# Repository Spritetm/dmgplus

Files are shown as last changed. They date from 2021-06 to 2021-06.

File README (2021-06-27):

GNUBOY README

  INTRO

Welcome to gnuboy, one of the few pieces of Free Software to emulate
the Game Boy handheld game console. Written in ANSI C with a few
optional assembler optimizations for particular cpus, gnuboy supports
a wide range of host systems, and has been tested successfully on:

  GNU/Linux
  FreeBSD
  OpenBSD
  BeOS
  Linux/390 (IBM S/390 Mainframe)
  SunOS/Sun Ultra60
  IRIX/SGI O2
  IRIX/SGI Indy
  AIX/Unknown
  DR-DOS
  MS-DOS
  Windows DOS box
  Windows 9x/NT/2k

Additionally, gnuboy should run on any other *nix variants that have
ANSI C compilers and that are remotely POSIX compliant. As gnuboy is
Free Software, you're welcome to fix any problems you encounter
building it for a particular system, or to port it to entirely new
systems.

  EMULATION

gnuboy emulates nearly all aspects of the (Color) Gameboy, including
all of the following and much more:

  Full GBZ80 instruction set.
  Scanline-based LCD engine.
  Ten sprites per scanline limit.
  Support for all CGB graphics extensions.
  Sprite DMA, HDMA, and GDMA.
  All four sound channels including digital samples.
  MBC1, MBC2, MBC3 (including clock), and MBC5 mappers.
  Wave pattern memory corruption when sound channel 3 is played.
  Pad, timer, divide counter, and other basic hardware registers.
  CGB double-speed CPU mode.

Aspects not emulated at this time include:

* Serial IO (link cable).
  Undocumented 'extra' ram in OAM space on Gameboy Color.
  All Super Gameboy extensions.
* GBC, HuC1, and HuC3 IR ports.
* Obscure mappers such as TAMA5.
  Sorting sprites by X coordinate in DMG mode.
  HALT instruction skipping in DMG mode.
  CPU stalls during HDMA and GDMA.

Only the two marked by * are known to affect the playability of
actual games or demos; the rest are just listed for completeness'
sake.

  FEATURES

In addition to basic emulation, gnuboy provides the following
features:

  Highly flexible keybinding and configuration subsystem.
  State saving and loading at any point.
  Very precise timing/synchronization, preserved across save/load.
  Joystick support on Linux, DOS, and all SDL-based ports.
  Fully customizable palettes for DMG games.
  Screen scaling by a factor of 2, 3, or 4 in all ports.
  Hardware-based screen scaling on platforms where it's available.
  Debug traces to stdout.
  Dynamic palette allocation when run in 256-color modes...
  OR simulated 3/3/2 bits per channel in 256-color modes.

For information on configuring and using these features, see the
additional documentation in the "docs" directory.

  COMPATIBILITY

Out of over 300 results reported by testers, all games are known to
work perfectly on gnuboy with the following exceptions:

  Fighting Phoenix (Japanese) may or may not work since it uses the
  HuC1 memory controller, which is not implemented properly. There has
  been no report either way so far.

  Pocket Bomberman (Japanese version, which uses HuC1) runs, but can
  be made to crash if the player jumps into the ceiling in the first
  level. It's not clear whether this bug is MBC-related, something
  else, or an actual bug in the original game.

  Monster Go! Go! Go! (Japanese) is unplayable. The cause of the
  problem is not fully known, but it's either a very bad dump or it's
  using some sort of specialized MBC that's not documented.

  Final Fantasy Adventure has visual problems with the fade between
  screens. Does not affect gameplay.

  Bubble Bobble 2 has some minor tile glitches right before gameplay
  actually begins. Cause unknown. Does not affect gameplay.

  Alone in the Dark is reported to have minor visual glitches. I
  haven't seen it myself so I can't judge their severity.

  Both new Zelda games are reported to have a visual glitch at the
  beginning of the game, and on certain other screens. I haven't seen
  the problem myself, but supposedly it impacts gameplay to some
  extent.

Please report any other incompatibilities discovered directly to
gnuboy@unix-fu.org, so that they can be documented and hopefully
fixed.

  FUTURE / WISHLIST

Here's a brief list of what may appear in gnuboy in the future:

  Screenshots.
  Integrated debugger.
  Super Gameboy support.
  Serial link over the internet.
  Serial link to a real Gameboy with a custom cable.
  Configurable color filters to provide more authentic LCD look.
  Custom colorization of DMG games on a per-tile basis.
  Support for more colorspaces in the hardware scaler.
  Recording audio.
  GBS player built from the same source tree.
  Full recording and playback of emulation.
  So-called "high level emulation" of certain typical dumb loops.

Features that are not likely to appear soon or at all include:

  Rumble support - this would be nice, but SDL doesn't seem to support
  force-feedback yet. We'll see about it in the long-term though.

  Eagle/2xSaI/etc. - probably not feasible since these libraries don't
  appear to be compatible with the terms of the GPL. We might work on
  our own interpolation engine eventually, but that's low priority.

  GUI/GUI-like features - such things are best handled by external
  front-ends. We might eventually add a mechanism for external
  programs to communicate with gnuboy and reconfigure it while it's
  running, however.

  Plugins - NO! The way I see it, plugins are just an attempt to work
  around the GPL. In any case, even if you are adding plugin support
  yourself, you are bound by the terms of the GPL when linking ANY
  code to gnuboy, including dynamic-linked modules. However we'd
  rather not deal with this mess to begin with.

  Compressed ROMs/Saves - this one is very iffy. On most systems, this
  is redundant; *nix users can just pipe the rom through a
  decompression program, and Windows users can just double-click or
  drag files from their favorite GUI unzipper program. Linking to zlib
  isn't really acceptable since it's massively bloated and we don't
  want to include it with gnuboy or add external dependencies. We may,
  however, write our own tiny decompressor to use at some point.

Ideas and suggestions for other features are welcome, but won't
necessarily be used. You're of course also free to add features
yourself, and if they fit well into the main tree they may eventually
get included in the official release. See the file HACKING for more
details on modifying and/or contributing.

  THANKS

Thanks goes out to everyone who's expressed interest in gnuboy by
writing -- users, porters, authors of other emulators, and so forth.
Apologies if we don't get a personal response out to everyone, but
either way, consider your feedback appreciated.

  EPILOGUE

OK, that looks like about it. More to come, stick around...

                                          -Laguna  <laguna@aerifal.cx>

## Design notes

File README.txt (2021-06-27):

These are various files for the DMGPlus project. Note that I did this over the time span
of about three years, so there's no plug-and-play recipe to build your own available;
I'd need to reverse my own work to provide that. As such, these files are only provided
as a reference, to plunder if you want to build something similar. For more information
about the DMGPlus project, refer to https://spritesmods.com/?art=dmgplus

The various subdirectories:

* kicad-pcb
This contains the PCB layout. Look at dmgplus-schematic.pdf in that directory if you only want
to look at the schematic without opening Kicad.

* fpga
This contains the Verilog sources for the Ice40 FPGA configuration. You need a proper 
Yosys/nextpnr/icestorm setup to build this.

* linux
This contains the gpio-matrix patch I had to apply to get multiple buttonpresses to work, as
well as the config I use to get the kernel startup to be fast.

* devicetree
The Linux kernel requires a custom device tree to get sound output, DPI RGB on the correct 
pins, and the mapping for the GPIO keyboard matrix; this generates that. Note that you need 
a device tree compiler (e.g. Debian package device-tree-compiler) to build this.

* spi-flash-reader
This compiles and runs under Raspbian. It allows you to read a GameBoy cartridge through the 
Ice40 FPGA via the SPI port. It also allows you to write the reproduction cartridges that are 
around, if you happen to have a similar model to mine.

This directory also contains an initial_init.sh script, which acts as a replacement init
script. It checks the cart inserted and starts up whatever's applicable.

* gnuboy
This is Gnuboy, modified to use the same SPI cart reading method to execute from the actual
cart that is inserted in the DMGPlus unit.

* conv_startupscreen
This is a tool to generate the binary ROM images that can be flashed into a cartridge to 
create a DMGPlus cart. The tool takes a png image that is used as a startup screen, a 
delay, and a game name. The FPGA will display the startup screen for the indicated delay,
the Raspberry Pi can use the game name to start up whatever is required.

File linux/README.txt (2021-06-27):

For posterity, this is:
- The config I used for the dmgplus
- The patch that adds multiple-key-press-detection to gpio-matrix-keypad

This is against the rpi-5.10.y branch of https://github.com/raspberrypi/linux. I used commit
5188f0cf6c768cc791b3283ab6a72cc02b4a2f99 as a basis.

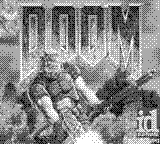
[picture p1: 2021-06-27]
conv_startupscreen/doom.png

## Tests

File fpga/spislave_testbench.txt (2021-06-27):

000
001
011
111
011
111
001
101
011
111
001
101
001
101
001
101
001
101
011
111
011
111
001
101
011
111
001
101
001
101
001
101
011
111
001
000

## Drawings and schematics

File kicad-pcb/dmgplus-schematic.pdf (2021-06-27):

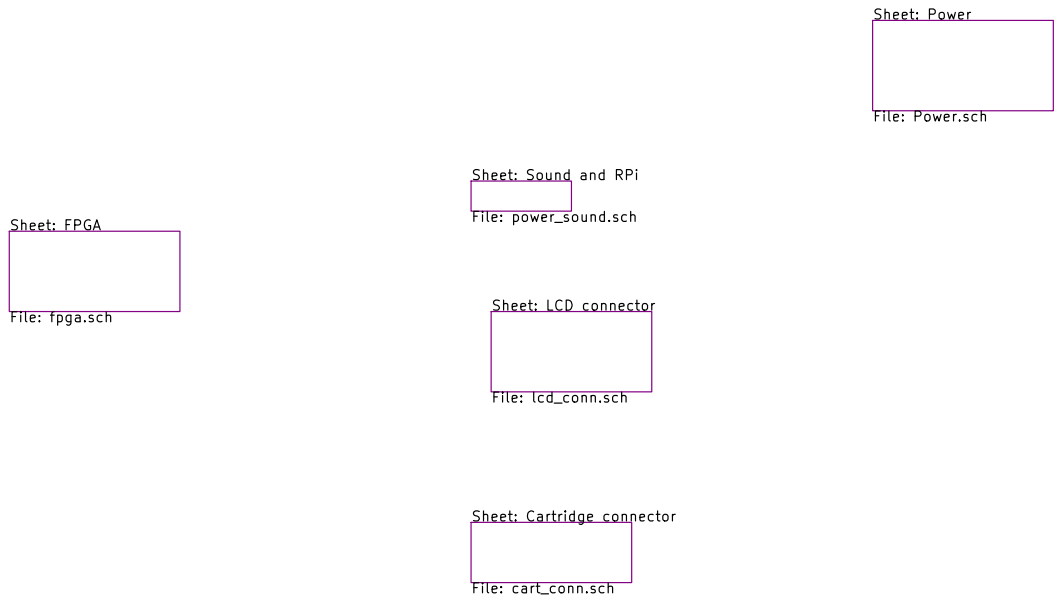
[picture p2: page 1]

Sheet: Sound and RPi File: power_sound.sch Sheet: LCD connector File: lcd_conn.sch Sheet: Cartridge connector File: cart_conn.sch Sheet: FPGA

File: dmgplus.sch Sheet: /
Id: 1/6 Title:

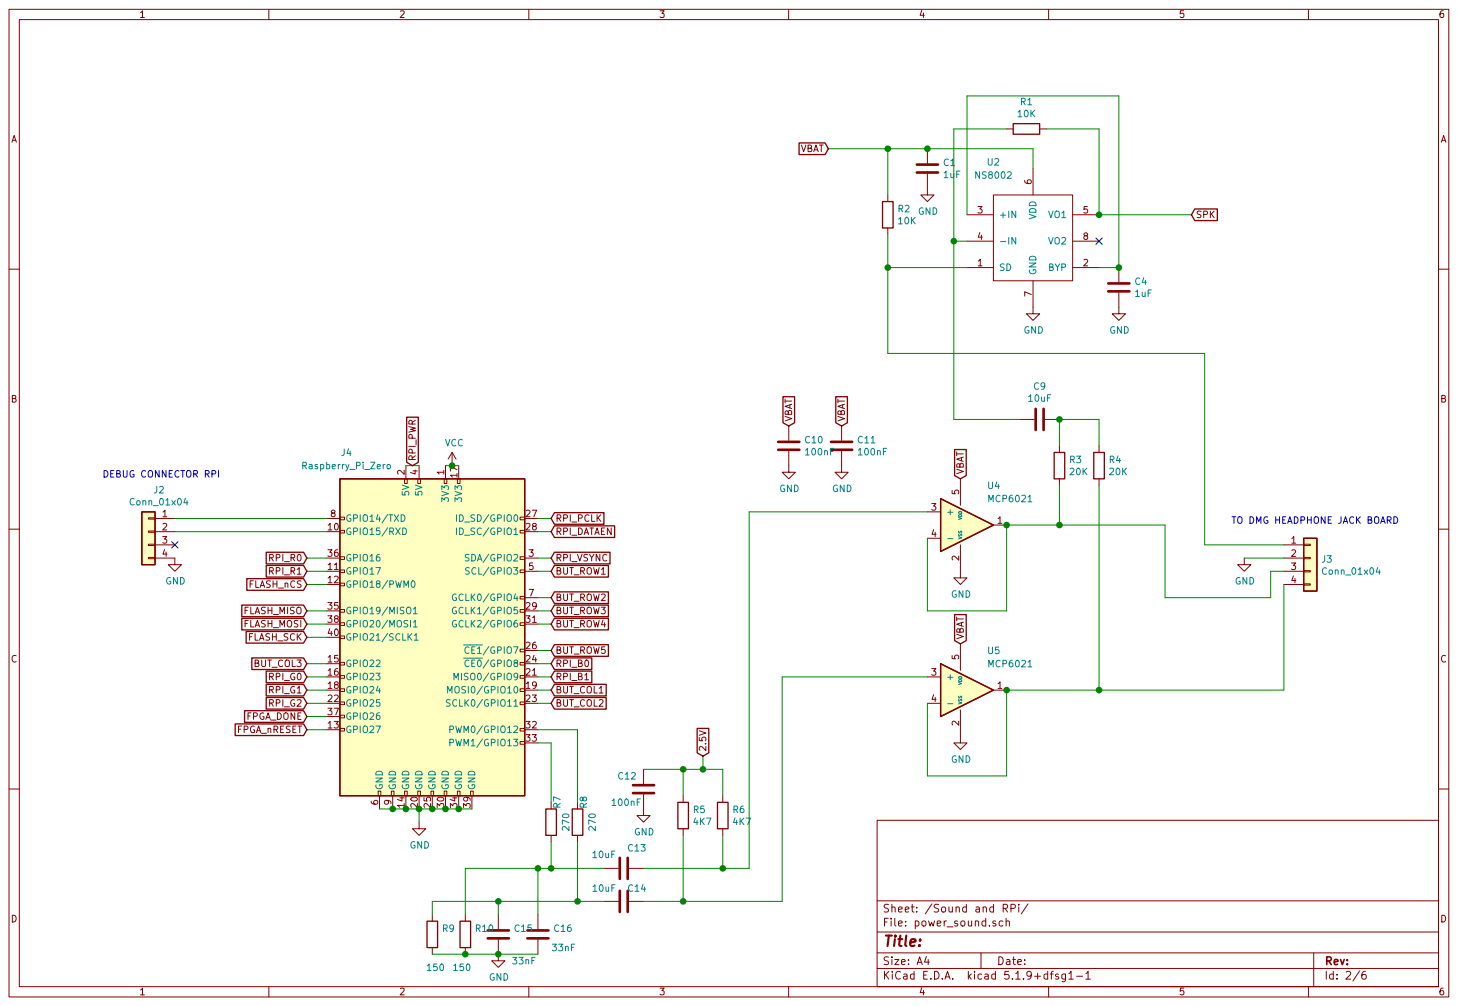
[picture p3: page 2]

File: power_sound.sch Sheet: /Sound and RPi/ C16

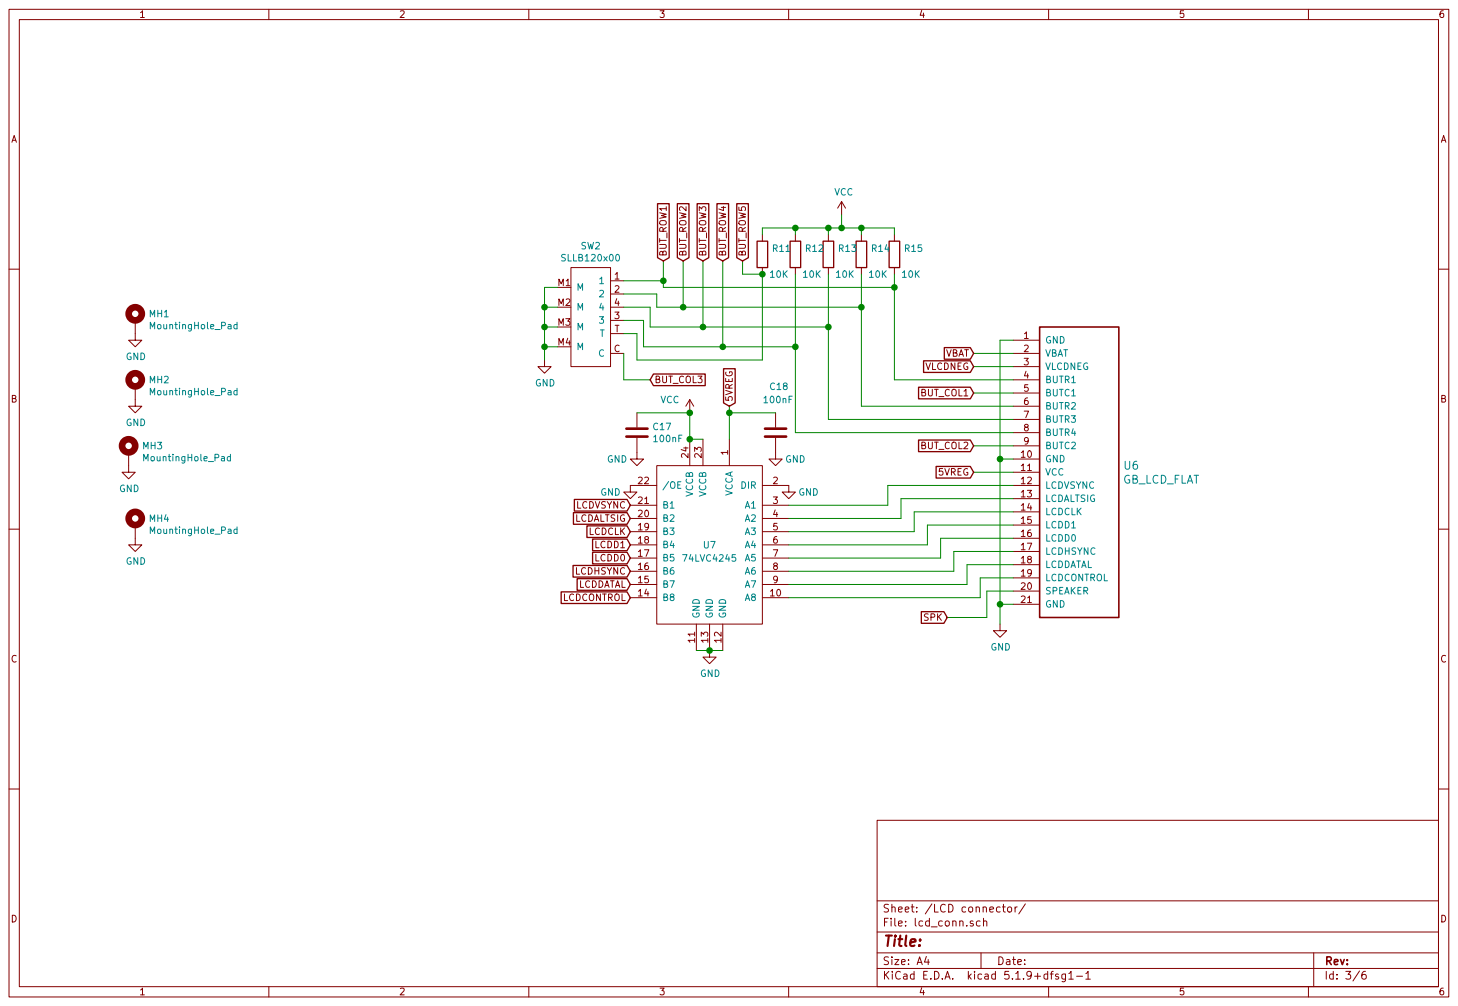
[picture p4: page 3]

1 A8 10 GND 11 GND 12 GND 13 B8 14 B7 15 B6 16 B5 17 B4 18 B3 19 DIR 2 B2 20 B1 21

LCDCLK 14
LCDD1 15
LCDD0 16
LCDHSYNC 17
LCDDATAL 18

File: lcd_conn.sch Sheet: /LCD connector/
Id: 3/6 Title:

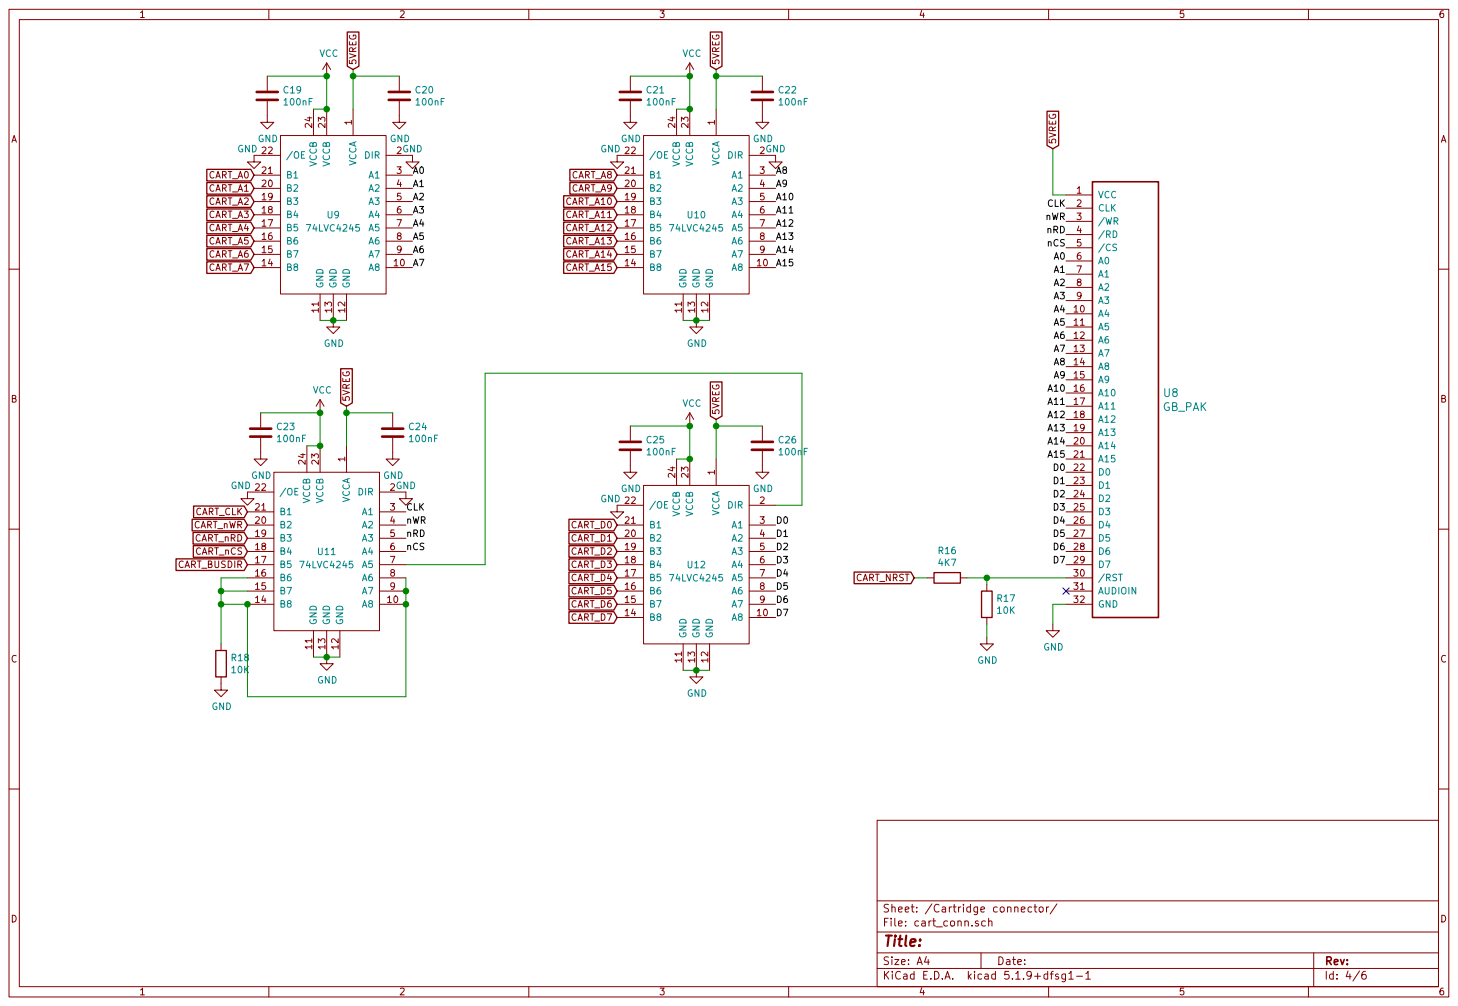
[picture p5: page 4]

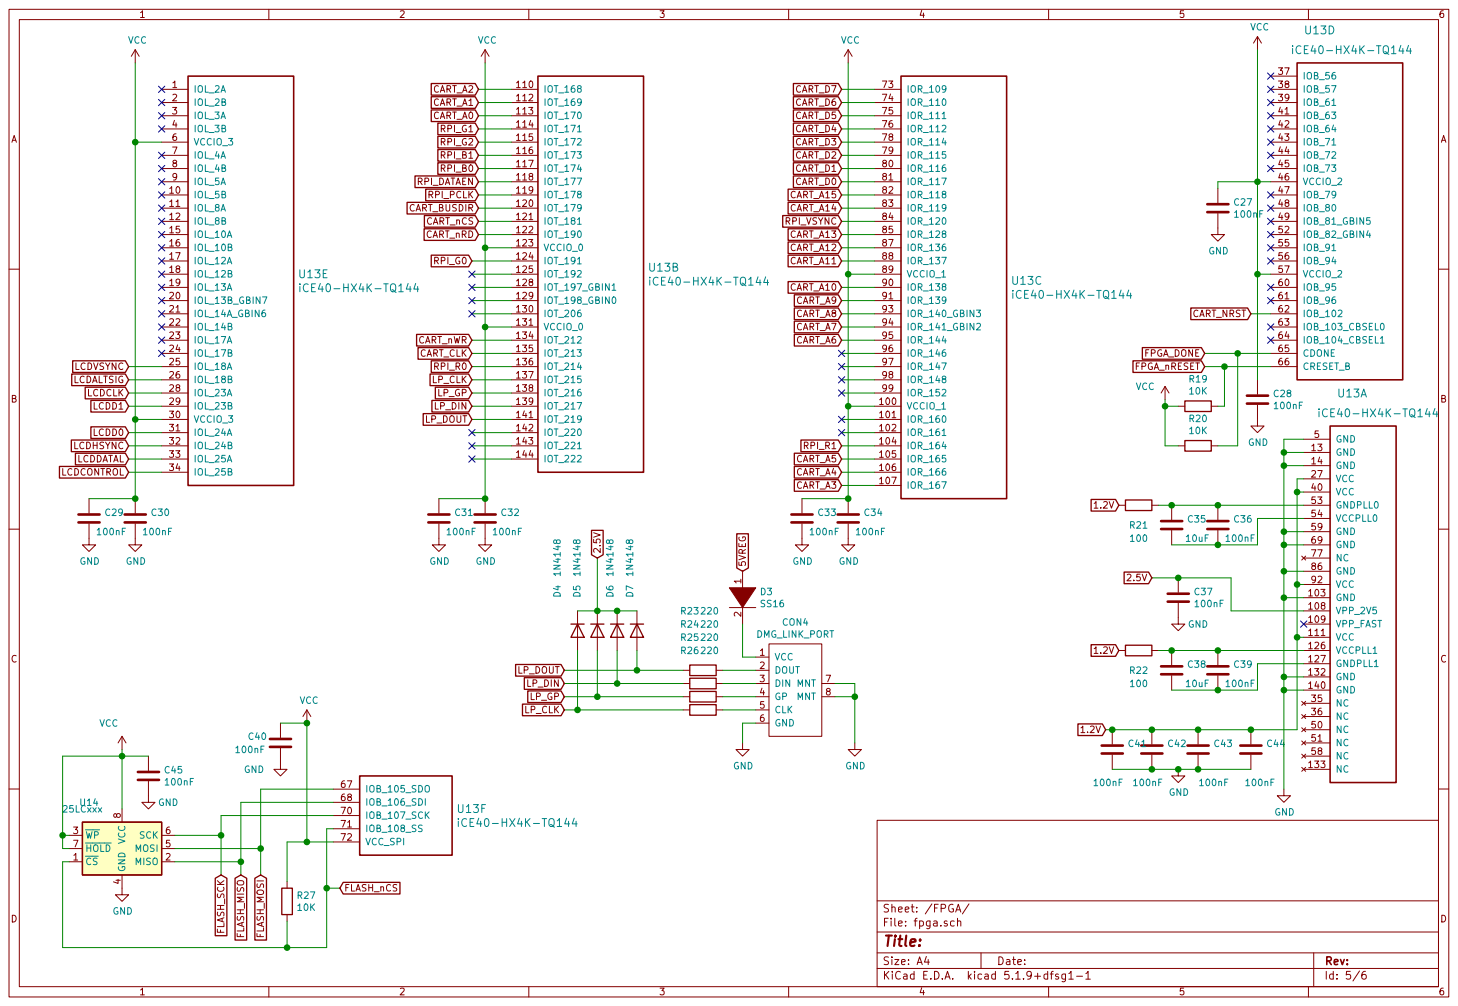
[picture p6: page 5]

File: fpga.sch Sheet: /FPGA/ C40

IOB_106_SDI 68
IOB_107_SCK 70

4 MOSI 5 SCK 6 HOLD 7 VCC

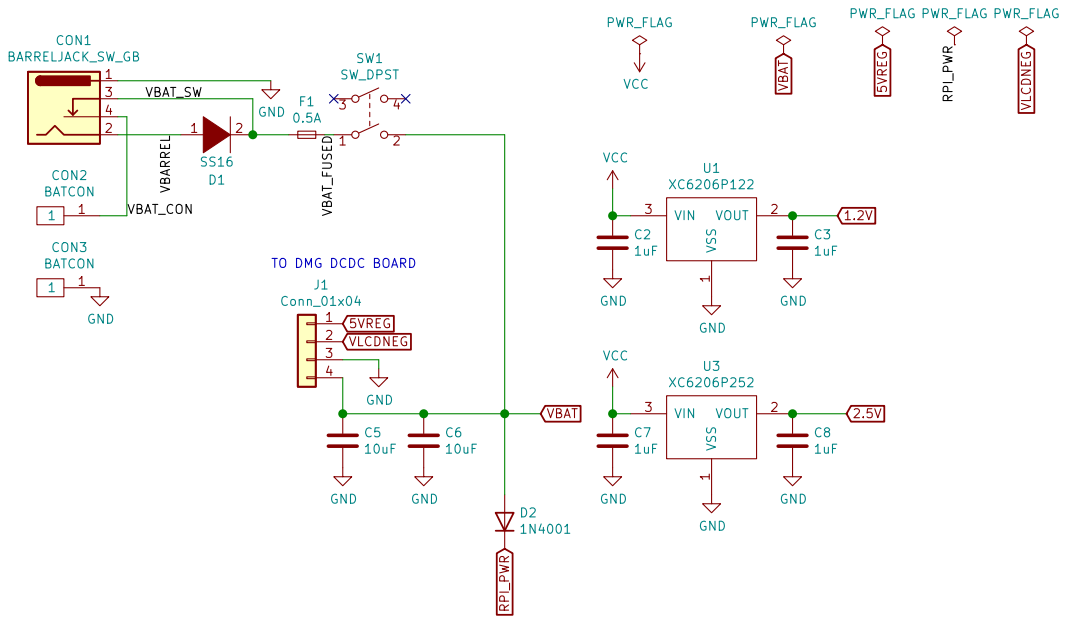
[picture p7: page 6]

Id: 6/6 Title: File: Power.sch Sheet: /Power/

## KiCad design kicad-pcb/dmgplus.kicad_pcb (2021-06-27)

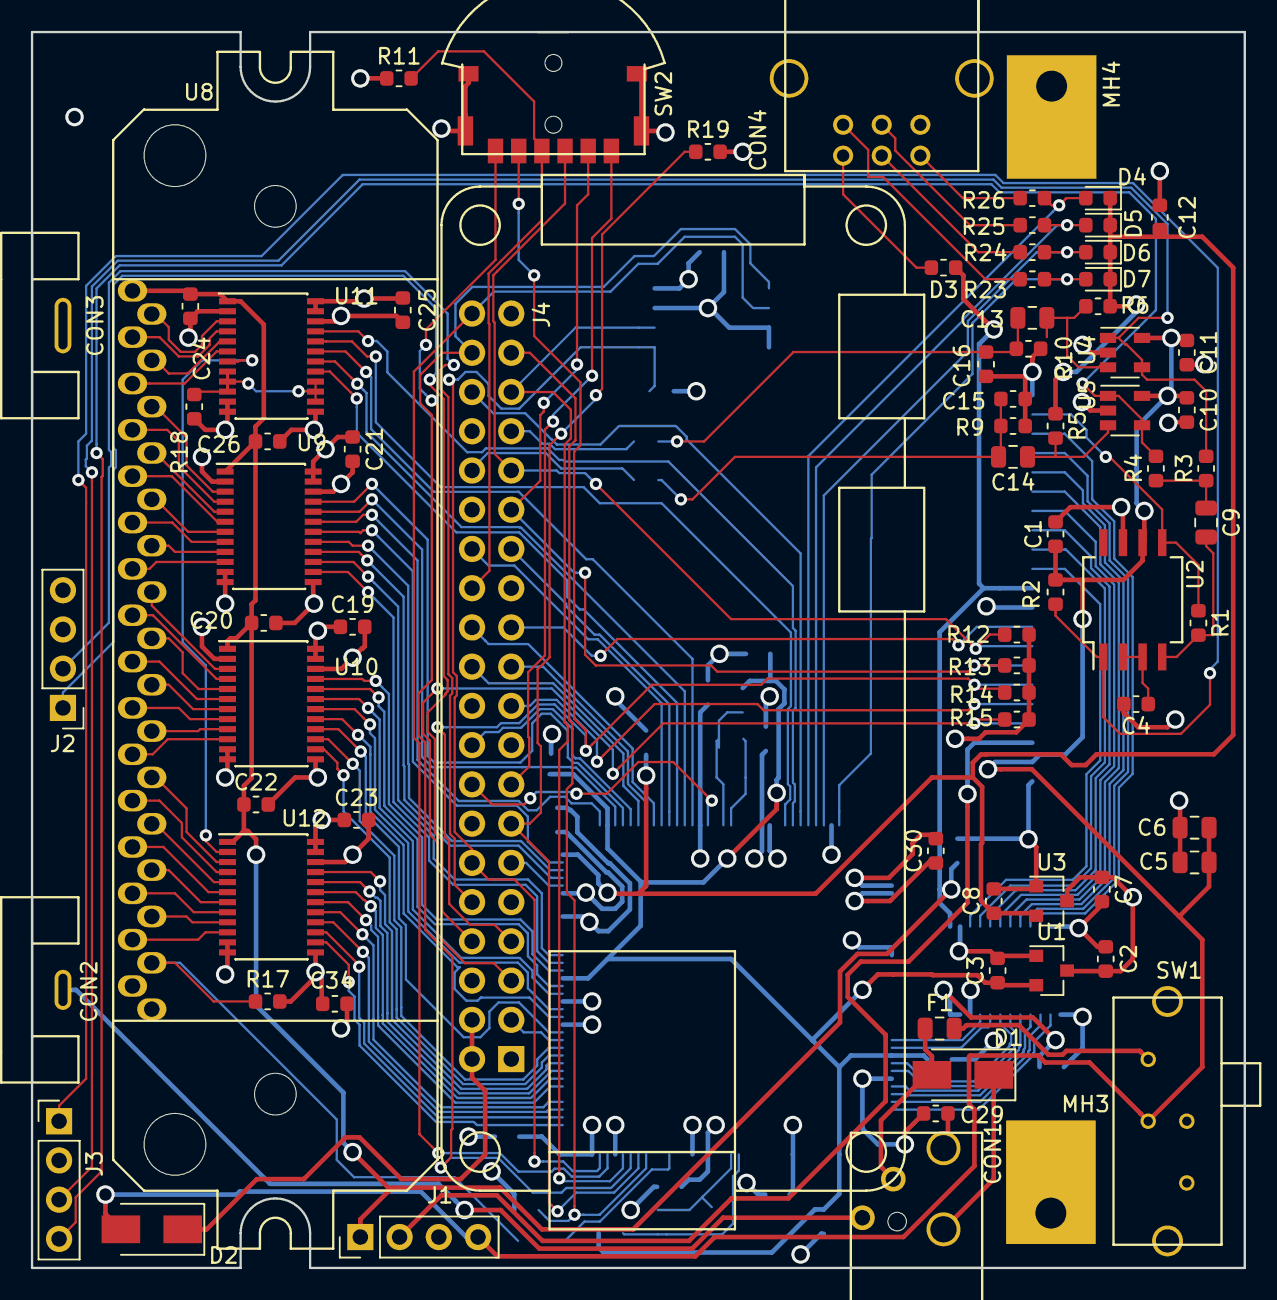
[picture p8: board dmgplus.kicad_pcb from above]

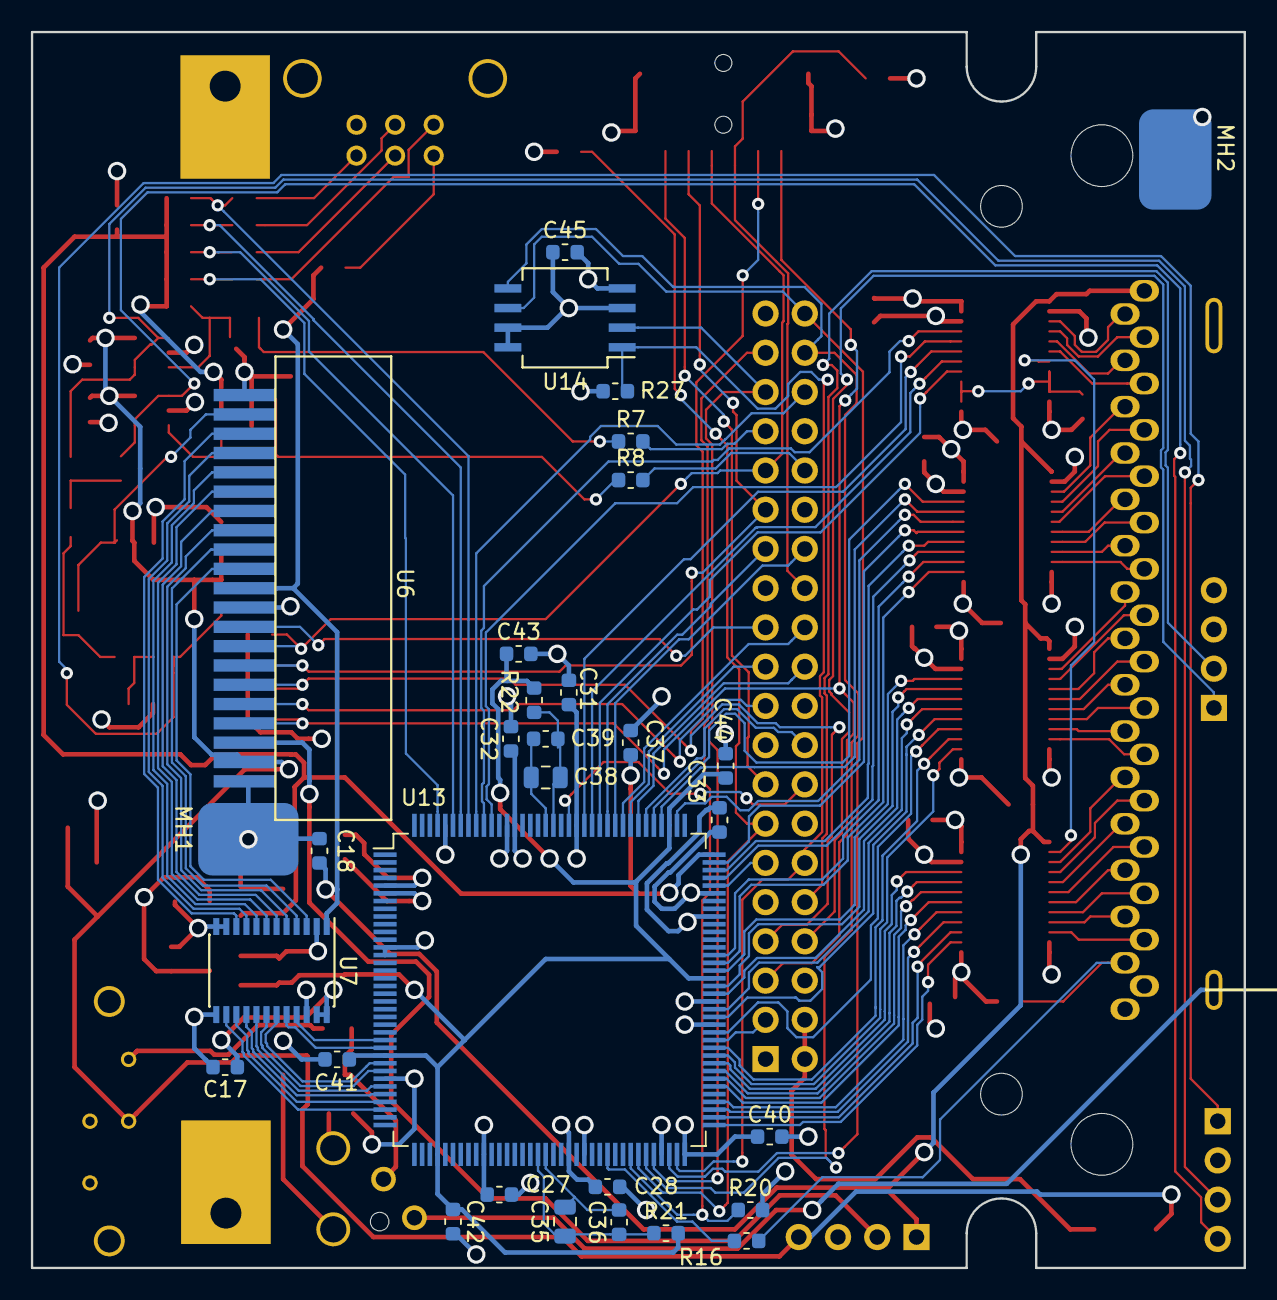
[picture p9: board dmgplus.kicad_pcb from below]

Board: 4 copper layers, 78.5 x 80.0 mm, 108 parts (31 on the bottom side), 141 nets.

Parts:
C1, C2, C3, C4, C7, C8: 1uF; C_0603_1608Metric
C5, C6, C9, C13, C14, C35, C38: 10uF; C_0805_2012Metric
C10, C11, C12, C17, C18, C19, C20, C21, C22, C23, C24, C25, C26, C27, C28, C29, C30, C31, C32, C33, C34, C36, C37, C39, C40, C41, C42, C43, C44, C45: 100nF; C_0603_1608Metric
C15, C16: 33nF; C_0603_1608Metric
CON1: BARRELJACK_SW_GB; dmg_pwrjack
CON2: BATCON; dmg_batcon_pos
CON3: BATCON; dmg_batcon_neg
CON4: DMG_LINK_PORT; dmg_linkport
D1: SS16; D_SMA
D2: 1N4001; D_SMA
D3: SS16; R_0603_1608Metric
D4, D5, D6, D7: 1N4148; D_0603_1608Metric
F1: 0.5A; Fuse_0805_2012Metric
J1, J2, J3: Conn_01x04; PinHeader_1x04_P2.54mm_Vertical
J4: Raspberry_Pi_Zero; Raspberry Pi Zero
MH1, MH2: MountingHole_Pad; dmg_grounding_square
MH3, MH4: MountingHole_Pad; dmg_groundhole_square
R1, R2, R11, R12, R13, R14, R15, R17, R18, R19, R20, R27: 10K; R_0603_1608Metric
R3, R4: 20K; R_0603_1608Metric
R5, R6, R16: 4K7; R_0603_1608Metric
R7, R8: 270; R_0603_1608Metric
R9, R10: 150; R_0603_1608Metric
R21, R22: 100; R_0603_1608Metric
R23, R24, R25, R26: 220; R_0603_1608Metric
SW1: SW_DPST; dmg_powersw
SW2: SLLB120x00; Alps_SLLB120x00
U1: XC6206P122; SOT-23
U2: NS8002; SO-8_5.3x6.2mm_P1.27mm
U3: XC6206P252; SOT-23
U4, U5: MCP6021; SOT-23-5
U6: GB_LCD_FLAT; fpc_conn_21pin
U7, U9, U10, U11, U12: 74LVC4245; TSSOP-24_4.4x7.8mm_P0.65mm
U8: GB_PAK; GB_CART_CONN
U13: iCE40-HX4K-TQ144; TQFP-144_20x20mm_P0.5mm
U14: 25LCxxx; SO-8_5.3x6.2mm_P1.27mm

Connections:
1.2V: C3.1, C41.1, C42.1, C43.1, C44.1, R21.2, R22.2, U1.2, U13.27, U13.40, U13.92, U13.111
2.5V: C8.1, C12.1, C37.1, D4.1, D5.1, D6.1, D7.1, R5.1, R6.1, U3.2, U13.108
5VREG: C18.1, C20.1, C22.1, C24.1, C26.1, D3.1, J1.1, U6.11, U7.1, U8.1, U9.1, U10.1, U11.1, U12.1
/Cartridge connector/A0: U8.6, U9.3
/Cartridge connector/A1: U8.7, U9.4
/Cartridge connector/A2: U8.8, U9.5
/Cartridge connector/A3: U8.9, U9.6
/Cartridge connector/A4: U8.10, U9.7
/Cartridge connector/A5: U8.11, U9.8
/Cartridge connector/A6: U8.12, U9.9
/Cartridge connector/A7: U8.13, U9.10
/Cartridge connector/A8: U8.14, U10.3
/Cartridge connector/A9: U8.15, U10.4
/Cartridge connector/A10: U8.16, U10.5
/Cartridge connector/A11: U8.17, U10.6
/Cartridge connector/A12: U8.18, U10.7
/Cartridge connector/A13: U8.19, U10.8
/Cartridge connector/A14: U8.20, U10.9
/Cartridge connector/A15: U8.21, U10.10
/Cartridge connector/CLK: U8.2, U11.3
/Cartridge connector/D0: U8.22, U12.3
/Cartridge connector/D1: U8.23, U12.4
/Cartridge connector/D2: U8.24, U12.5
/Cartridge connector/D3: U8.25, U12.6
/Cartridge connector/D4: U8.26, U12.7
/Cartridge connector/D5: U8.27, U12.8
/Cartridge connector/D6: U8.28, U12.9
/Cartridge connector/D7: U8.29, U12.10
/Cartridge connector/nCS: U8.5, U11.6
/Cartridge connector/nRD: U8.4, U11.5
/Cartridge connector/nWR: U8.3, U11.4
/Power/VBARREL: CON1.2, D1.1
/Power/VBAT_CON: CON1.4, CON2.1
/Power/VBAT_FUSED: F1.2, SW1.1
/Power/VBAT_SW: CON1.3, D1.2, F1.1
BUT_COL1: J4.19, U6.5
BUT_COL2: J4.23, U6.9
BUT_COL3: J4.15, SW2.C
BUT_ROW1: J4.5, R15.2, SW2.1, U6.4
BUT_ROW2: J4.7, R14.2, SW2.2, U6.6
BUT_ROW3: J4.29, R13.2, SW2.4, U6.7
BUT_ROW4: J4.31, R12.2, SW2.3, U6.8
BUT_ROW5: J4.26, R11.2, SW2.T
CART_A0: U9.21, U13.113
CART_A1: U9.20, U13.112
CART_A2: U9.19, U13.110
CART_A3: U9.18, U13.107
CART_A4: U9.17, U13.106
CART_A5: U9.16, U13.105
CART_A6: U9.15, U13.95
CART_A7: U9.14, U13.94
CART_A8: U10.21, U13.93
CART_A9: U10.20, U13.91
CART_A10: U10.19, U13.90
CART_A11: U10.18, U13.88
CART_A12: U10.17, U13.87
CART_A13: U10.16, U13.85
CART_A14: U10.15, U13.83
CART_A15: U10.14, U13.82
CART_BUSDIR: U11.17, U13.120
CART_CLK: U11.21, U13.135
CART_D0: U12.21, U13.81
CART_D1: U12.20, U13.80
CART_D2: U12.19, U13.79
CART_D3: U12.18, U13.78
CART_D4: U12.17, U13.76
CART_D5: U12.16, U13.75
CART_D6: U12.15, U13.74
CART_D7: U12.14, U13.73
CART_NRST: R16.2, U13.62
CART_nCS: U11.18, U13.121
CART_nRD: U11.19, U13.122
CART_nWR: U11.20, U13.134
FLASH_MISO: J4.35, U13.68, U14.2
FLASH_MOSI: J4.38, U13.67, U14.5
FLASH_SCK: J4.40, U13.70, U14.6
FLASH_nCS: J4.12, R27.2, U13.71, U14.1
FPGA_DONE: J4.37, R20.1, U13.65
FPGA_nRESET: J4.13, R19.1, U13.66
GND: C1.2, C2.2, C3.2, C4.2, C5.2, C6.2, C7.2, C8.2, C10.2, C11.2, C12.2, C15.2, C16.2, C17.2, C18.2, C19.2, C20.2, C21.2, C22.2, C23.2, C24.2, C25.2, C26.2, C27.2, C28.2, C29.2, C30.2, C31.2, C32.2, C33.2, C34.2, C37.2, C40.2, C41.2, C42.2, C43.2, C44.2, C45.2, CON1.1, CON3.1, CON4.6, CON4.7, CON4.8, J1.3, J2.4, J3.2, J4.6, J4.9, J4.14, J4.20, J4.25, J4.30, J4.34, J4.39, MH1.1, MH2.1, MH3.1, MH4.1, R9.2, R10.2, R17.2, R18.2, SW2.M1, SW2.M2, SW2.M3, SW2.M4, U1.1, U2.7, U3.1, U4.2, U5.2, U6.1, U6.10, U6.21, U7.2, U7.11, U7.12, U7.13, U7.22, U8.32, U9.2, U9.11, U9.12, U9.13, U9.22, U10.2, U10.11, U10.12, U10.13, U10.22, U11.2, U11.11, U11.12, U11.13, U11.22, U12.11, U12.12, U12.13, U12.22, U13.5, U13.13, U13.14, U13.59, U13.69, U13.86, U13.103, U13.132, U13.140, U14.4
LCDALTSIG: U7.20, U13.26
LCDCLK: U7.19, U13.28
LCDCONTROL: U7.14, U13.34
LCDD0: U7.17, U13.31
LCDD1: U7.18, U13.29
LCDDATAL: U7.15, U13.33
LCDHSYNC: U7.16, U13.32
LCDVSYNC: U7.21, U13.25
LP_CLK: D4.2, R26.2, U13.137
LP_DIN: D6.2, R24.2, U13.139
LP_DOUT: D7.2, R23.2, U13.141
LP_GP: D5.2, R25.2, U13.138
unnamed: C4.1, U2.2, U2.3
unnamed: C9.1, R3.1, R4.1
unnamed: C9.2, R1.2, U2.4
unnamed: C13.1, C16.1, R7.1, R10.1
unnamed: C13.2, R6.2, U4.3
unnamed: C14.1, R5.2, U5.3
unnamed: C14.2, C15.1, R8.1, R9.1
unnamed: C35.1, C36.1, R21.1, U13.53
unnamed: C35.2, C36.2, U13.54
unnamed: C38.1, C39.1, R22.1, U13.126
unnamed: C38.2, C39.2, U13.127
unnamed: CON4.1, D3.2
unnamed: CON4.2, R23.1
unnamed: CON4.3, R24.1
unnamed: CON4.4, R25.1
unnamed: CON4.5, R26.1
unnamed: J2.1, J4.8
unnamed: J2.2, J4.10
unnamed: J3.1, R2.2, U2.1
unnamed: J3.3, R3.2, U4.1, U4.4
unnamed: J3.4, R4.2, U5.1, U5.4
unnamed: J4.32, R8.2
unnamed: J4.33, R7.2
unnamed: R16.1, R17.1, U8.30
unnamed: R18.1, U11.8, U11.9, U11.10, U11.14, U11.15, U11.16
unnamed: U6.12, U7.3
unnamed: U6.13, U7.4
unnamed: U6.14, U7.5
unnamed: U6.15, U7.6
unnamed: U6.16, U7.7
unnamed: U6.17, U7.8
unnamed: U6.18, U7.9
unnamed: U6.19, U7.10
unnamed: U11.7, U12.2
RPI_B0: J4.24, U13.117
RPI_B1: J4.21, U13.116
RPI_DATAEN: J4.28, U13.118
RPI_G0: J4.16, U13.124
RPI_G1: J4.18, U13.114
RPI_G2: J4.22, U13.115
RPI_PCLK: J4.27, U13.119
RPI_PWR: D2.1, J4.2, J4.4
RPI_R0: J4.36, U13.136
RPI_R1: J4.11, U13.104
RPI_VSYNC: J4.3, U13.84
SPK: R1.1, U2.5, U6.20
VBAT: C1.1, C5.1, C6.1, C10.1, C11.1, D2.2, J1.4, R2.1, SW1.2, U2.6, U4.5, U5.5, U6.2
VCC: C2.1, C7.1, C17.1, C19.1, C21.1, C23.1, C25.1, C27.1, C28.1, C29.1, C30.1, C31.1, C32.1, C33.1, C34.1, C40.1, C45.1, J4.1, J4.17, R11.1, R12.1, R13.1, R14.1, R15.1, R19.2, R20.2, R27.1, U1.3, U3.3, U7.23, U7.24, U9.23, U9.24, U10.23, U10.24, U11.23, U11.24, U12.23, U12.24, U13.6, U13.30, U13.46, U13.57, U13.72, U13.89, U13.100, U13.123, U13.131, U14.3, U14.7, U14.8
VLCDNEG: J1.2, U6.3

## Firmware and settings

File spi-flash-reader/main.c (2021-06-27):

//Code to interface with the FPGA to read (and write, if possible) a GB cart.

/*
 * ----------------------------------------------------------------------------
 * "THE BEER-WARE LICENSE" (Revision 42):
 * Jeroen Domburg <jeroen@spritesmods.com> wrote this file. As long as you retain 
 * this notice you can do whatever you want with this stuff. If we meet some day, 
 * and you think this stuff is worth it, you can buy me a beer in return. 
 * ----------------------------------------------------------------------------
 */

#include <stdint.h>
#include <unistd.h>
#include <stdio.h>
#include <stdlib.h>
#include <unistd.h>
#include <getopt.h>
#include <fcntl.h>
#include <sys/ioctl.h>
#include <linux/types.h>
#include <linux/spi/spidev.h>
#include <string.h>
#include "hexdump.h"

#define ARRAY_SIZE(a) (sizeof(a) / sizeof((a)[0]))

static void die(const char *s) {
	perror(s);
	exit(1);
}


typedef struct __attribute__((packed)) {
	uint8_t entry_point[4];
	uint8_t logo[0x30];
	uint8_t title[15];
	uint8_t cgb_flag;
	uint16_t licensee_new;
	uint8_t sgb_flag;
	uint8_t type;
	uint8_t rom_size;
	uint8_t ram_size;
	uint8_t dest_code;
	uint8_t licensee_old;
	uint8_t maskrom_ver;
	uint8_t hdr_chsum;
	uint16_t rom_checksum;
} gb_header_t;

typedef struct {
	int no;
	const char *desc;
	int sz;
} no_desc_t;

const no_desc_t cart_type_desc[]={
	{0x00, "ROM ONLY"},
	{0x01, "MBC1"},
	{0x02, "MBC1+RAM"},
	{0x03, "MBC1+RAM+BATTERY"},
	{0x05, "MBC2"},
	{0x06, "MBC2+BATTERY"},
	{0x08, "ROM+RAM"},
	{0x09, "ROM+RAM+BATTERY"},
	{0x0B, "MMM01"},
	{0x0C, "MMM01+RAM"},
	{0x0D, "MMM01+RAM+BATTERY"},
	{0x0F, "MBC3+TIMER+BATTERY"},
	{0x10, "MBC3+TIMER+RAM+BATTERY"},
	{0x11, "MBC3"},
	{0x12, "MBC3+RAM"},
	{0x13, "MBC3+RAM+BATTERY"},
	{0x19, "MBC5"},
	{0x1A, "MBC5+RAM"},
	{0x1B, "MBC5+RAM+BATTERY"},
	{0x1C, "MBC5+RUMBLE"},
	{0x1D, "MBC5+RUMBLE+RAM"},
	{0x1E, "MBC5+RUMBLE+RAM+BATTERY"},
	{0x20, "MBC6"},
	{0x22, "MBC7+SENSOR+RUMBLE+RAM+BATTERY"},
	{0xFC, "POCKET CAMERA"},
	{0xFD, "BANDAI TAMA5"},
	{0xFE, "HuC3"},
	{0xFF, "HuC1+RAM+BATTERY"},
	{0, NULL}
};

const no_desc_t rom_size_desc[]={
	{0x00, "32KByte (2 banks, no mbc)"},
	{0x01, "64KByte (4 banks)"},
	{0x02, "128KByte (8 banks)"},
	{0x03, "256KByte (16 banks)"},
	{0x04, "512KByte (32 banks)"},
	{0x05, "1MByte (64 banks)  - only 63 banks used by MBC1"},
	{0x06, "2MByte (128 banks) - only 125 banks used by MBC1"},
	{0x07, "4MByte (256 banks)"},
	{0x08, "8MByte (512 banks)"},
	{0x52, "1.1MByte (72 banks)"},
	{0x53, "1.2MByte (80 banks)"},
	{0x54, "1.5MByte (96 banks)"},
	{0, NULL}
};

const no_desc_t ram_size_desc[]={
	{0x01, "2 KBytes"},
	{0x02, "8 Kbytes"},
	{0x03, "32 KBytes (4 banks of 8KBytes each)"},
	{0x04, "128 KBytes (16 banks of 8KBytes each)"},
	{0, NULL}
};

const no_desc_t lang_desc[]={
	{0x05, "64 KBytes (8 banks of 8KBytes each)00h - Japanese"},
	{0x01, "Non-Japanese"},
	{0, NULL}
};

const uint8_t ninty_logo[0x30]={
	0xCE, 0xED, 0x66, 0x66, 0xCC, 0x0D, 0x00, 0x0B, 0x03, 0x73, 
	0x00, 0x83, 0x00, 0x0C, 0x00, 0x0D, 0x00, 0x08, 0x11, 0x1F, 
	0x88, 0x89, 0x00, 0x0E, 0xDC, 0xCC, 0x6E, 0xE6, 0xDD, 0xDD, 
	0xD9, 0x99, 0xBB, 0xBB, 0x67, 0x63, 0x6E, 0x0E, 0xEC, 0xCC, 
	0xDD, 0xDC, 0x99, 0x9F, 0xBB, 0xB9, 0x33, 0x3E
};

int get_rom_bank_count(gb_header_t *hdr) {
	int v=hdr->rom_size;
	if (v<=8) {
		return 2*(1<<v);
	}
	if (v==0x52) return 72;
	if (v==0x53) return 80;
	if (v==0x54) return 96;
	return 2; //assume 32K rom
}

const char *select_desc(int no, const no_desc_t *desc) {
	static const char *ret="(unknown)";
	int i=0;
	while (desc[i].desc!=NULL) {
		if (desc[i].no==no) ret=desc[i].desc;
		i++;
	}
	return ret;
}

void show_gb_hdr_info(gb_header_t *hdr) {
	char title[17]={0};
	for (int i=0; i<16; i++) {
		if (hdr->title[i]==0 || hdr->title[i]>96) break;
		title[i]=hdr->title[i];
	}
	printf("Cart title: %s\n", title);
	printf("Cart type: %s\n", select_desc(hdr->type, cart_type_desc));
	printf("Cart size: %s\n", select_desc(hdr->rom_size, rom_size_desc));
	printf("Cart ram size: %s\n", select_desc(hdr->ram_size, ram_size_desc));
}


void gbcart_read(int fd, uint32_t addr, uint32_t len, uint8_t *buff) {
	uint8_t tx[3]={0};
	tx[0]=(addr>>8)&0x7f;
	tx[1]=addr&0xff;
	struct spi_ioc_transfer tr[3]={
		{
			.tx_buf = (unsigned long)tx,
			.len = 3,
			.cs_change=0
		},{
			.rx_buf=(unsigned long)buff,
			.len=len,
//			.delay_usecs=100,
			.cs_change=1
		},{
			.delay_usecs=5,
			.cs_change=1
		}
	};

	int ret = ioctl(fd, SPI_IOC_MESSAGE(3), tr);
	if (ret < 1) die("can't send spi message");
}

uint8_t gbcart_read_byte(int fd, uint32_t addr) {
	uint8_t ret;
	gbcart_read(fd, addr, 1, &ret);
	return ret;
}

void gbcart_write(int fd, uint32_t addr, uint32_t len, uint8_t *buff) {
	uint8_t tx[2]={0};
	tx[0]=(addr>>8)|0x80;
	tx[1]=addr&0xff;
	struct spi_ioc_transfer tr[3]={
		{
			.tx_buf = (unsigned long)tx,
			.len = 2,
			.cs_change=0
		},{
			.tx_buf=(unsigned long)buff,
			.len=len,
			.cs_change=1
		},{
			.delay_usecs=2,
			.cs_change=1
		}
	};

	int ret = ioctl(fd, SPI_IOC_MESSAGE(3), tr);
	if (ret < 1) die("can't send spi message");
}

void gbcart_write_byte(int fd, uint32_t addr, uint8_t byte) {
	gbcart_write(fd, addr, 1, &byte);
}

uint8_t mangle_flashchip_data(uint8_t byte) {
	uint8_t frobbyte=byte&0xFC;
	if (byte&1) frobbyte|=2;
	if (byte&2) frobbyte|=1;
	return frobbyte;
}

void poke_flashchip(int fd, int addr, int byte) {
	gbcart_write_byte(fd, addr, mangle_flashchip_data(byte));
}

int validate_cfi_data(uint8_t *buf) {
	if (buf[0x20]!='Q' || buf[0x22]!='R' || buf[0x24]!='Y') {
		printf("CFI data invalid. No flash cart?\n");
		return 0;
	}
	int n=buf[0x4E];
	printf("Found flash device: %d Kib\n", (1<<(n-10)));
}

void flash_wait_toggle(int fd, int addr) {
	uint8_t b1[2], b2[2];
	do {
		gbcart_read(fd, addr, 2, b1);
		gbcart_read(fd, addr, 1, b2);
//		printf("%02X %02X\n", b1[0], b2[0]);
	} while (b1[0]!=b2[0]);
}


int main(int argc, char *argv[]) {
	int ret = 0;

#if 0
	system("raspi-gpio set 18 op");
	system("raspi-gpio set 19 a4");
	system("raspi-gpio set 20 a4");
	system("raspi-gpio set 21 a4");
#endif
	
	char *dumpfile=NULL;
	int check=0;
	int dowrite=0;
	int doerase=0;
	int getname=0;
	for (int i=1; i<argc; i++) {
		if (strcmp(argv[i], "-check")==0) {
			check=1;
		} else if (strcmp(argv[i], "-getname")==0) {
			getname=1;
		} else if (strcmp(argv[i], "-write")==0) {
			dowrite=1;
		} else if (strcmp(argv[i], "-erase")==0) {
			doerase=1;
		} else if (dumpfile==NULL) {
			dumpfile=argv[i];
		} else {
			printf("Error: did not understand %s\n", argv[i]);
			printf("Usage: %s [-check] [-getname] [-write [-erase]] [dumpfile.bin]\n", argv[0]);
			exit(1);
		}
	}

	const char *device="/dev/spidev1.0";
	int mode=SPI_MODE_0|SPI_CS_HIGH;
	int speed=8000000;
	int delay_us=0;
	int bits=8;

	int fd = open(device, O_RDWR);
	if (fd < 0) die("can't open device");
	ret = ioctl(fd, SPI_IOC_WR_MODE, &mode);
	if (ret == -1) die("can't set spi mode");
	ret = ioctl(fd, SPI_IOC_WR_BITS_PER_WORD, &bits);
	if (ret == -1) die("can't set bits per word");
	ret = ioctl(fd, SPI_IOC_WR_MAX_SPEED_HZ, &speed);
	if (ret == -1) die("can't set max speed hz");

	gb_header_t hdr={0};
	gbcart_read(fd, 0x100, sizeof(hdr), (uint8_t*)&hdr);
	
	if (check || getname) {
		int hdr_ok=1;
		int logo_ok=1;
		int is_dmgplus=0;
		if (check) show_gb_hdr_info(&hdr);
		if (memcmp(hdr.logo, ninty_logo, 0x30)!=0) {
			hdr_ok=0;
			logo_ok=0;
			if (check) printf("Header check failed: Nintendo logo data corrupted.\n");
		}
		uint8_t chs=0;
		uint8_t *chsmem=(uint8_t*)&hdr.title;
		for (int i=0; i<0x19; i++) chs=chs-chsmem[i]-1;
		if (chs!=hdr.hdr_chsum) {
			hdr_ok=0;
			if (check) printf("Header check failed: Checksum error (calc %02X read %02X).\n", chs, hdr.hdr_chsum);
		}
		if (logo_ok) {
			if (memcmp(hdr.entry_point, "DMG+", 4)==0) {
				if (check) printf("Cart is DMGPlus dummy cart\n");
				is_dmgplus=1;
			}
		}
		if (getname) {
			if (hdr_ok) {
				printf("%s\n", hdr.title);
			} else if (is_dmgplus) {
				char buff[128];
				gbcart_read(fd, 0x0, 128, (uint8_t*)buff);
				printf("%s\n", buff);
			} else {
				printf("-\n");
			}
		}

		if (hdr_ok) return 0;
		if (is_dmgplus) return 2;
		return 1;
	}

	if (dumpfile && !dowrite) {
		show_gb_hdr_info(&hdr);
		FILE *out=fopen(dumpfile, "wb");
		if (out==NULL) die(dumpfile);
		uint8_t rdata[256];
		int bankcnt=get_rom_bank_count(&hdr);

		for (int bankno=0; bankno<bankcnt; bankno++) {
			int addr;
			if (bankno==0) {
				addr=0;
			} else {
				addr=0x4000;
				uint8_t w[1]={bankno};
				gbcart_write(fd, 0x2000, 1, w);
			}
			int chs=0;
			printf("Reading bank %d of %d at 0x%x...\n", bankno, bankcnt, addr);
			for (int j=0; j<16*1024; j+=sizeof(rdata)) {
				gbcart_read(fd, addr+j, sizeof(rdata), rdata);
				fwrite(rdata, sizeof(rdata), 1, out);
				for (int i=0; i<sizeof(rdata); i++) chs+=rdata[i];
			}
			chs=(chs&0xffff)+(chs>>16);
			chs=(chs&0xffff)+(chs>>16);
			printf("Checksum: %x\n", chs);
		}
		fclose(out);
	}

	if (dumpfile && dowrite) {
		//Idea: Write bank to 0x2000 (0-n). Bank shows up at 4000-7FFF. Use that to poke the flash
		//chip. (That also messes with the RAM enable and mapping; soit.)
		printf("Checking flash cart...\n");
		gbcart_write_byte(fd, 0x2000, 0); //switch to bank 0
		poke_flashchip(fd, 0x00, 0xF0); //reset
		poke_flashchip(fd, 0x00, 0xF0); //reset

		poke_flashchip(fd, 0xAA, 0x98); //CFI query
		uint8_t buf[100];
		gbcart_read(fd, 0, 0x100, buf);
		poke_flashchip(fd, 0, 0); //exit CFI query
		for (int i=0; i<100; i++) buf[i]=mangle_flashchip_data(buf[i]);
		int r=validate_cfi_data(buf);
		if (!r) return 1;
		
		FILE *rom=fopen(dumpfile, "rb");
		if (rom==NULL) die(dumpfile);
		
		if (doerase) {
			printf("Erasing chip...\n");
			poke_flashchip(fd, 0x0, 0x0a);
			gbcart_write_byte(fd, 0x2000, 0x0); //switch to bank
			poke_flashchip(fd, 0x2100, 0xf4);
			poke_flashchip(fd, 0x4000, 0xf0);

			poke_flashchip(fd, 0xaaa, 0xaa);
			poke_flashchip(fd, 0x555, 0x55);
			poke_flashchip(fd, 0xaaa, 0x80);
			poke_flashchip(fd, 0xaaa, 0xaa);
			poke_flashchip(fd, 0x555, 0x55);
			poke_flashchip(fd, 0xaaa, 0x10); //erase chip
//			poke_flashchip(fd, 0x0000, 0x30); //erase sector 0
			flash_wait_toggle(fd, 0);

			int is_erased=0;
			while (!is_erased) {
				uint8_t data[1024];
				is_erased=1;
				gbcart_read(fd, 0x4000, 1024, data);
				printf("%x %x %x %x\n", data[0], data[1], data[0], data[1]);
				for (int i=0; i<1024; i++) {
					if (data[i]!=0xff) {
						is_erased=0;
						break;
					}
				}
			}
			printf("Erased.\n");
		}
		printf("Writing...\n");
		int bank=0;
		uint8_t rombank[16*1024];
		while (fread(rombank, 1, 16*1024, rom)>0) {
			printf("Bank %d\n", bank);
#if 0
			gbcart_write_byte(fd, 0x2000, bank); //switch to bank
			poke_flashchip(fd, 0x2100, 0xf4);
			for (int i=0; i<16*256; i+=4) {
				gbcart_write_byte(fd, 0x2000, bank); //switch to bank
				poke_flashchip(fd, 0x2100, 0xf4);
				//Send quad write command

				poke_flashchip(fd, 0x4000, 0xF0); //reset flash chip
				poke_flashchip(fd, 0xaaa, 0x56); //quad write
				gbcart_write(fd, i+0x4000, 4, &rombank[i]);
				uint8_t rb[4];
				for (int retry=2000; retry>0; retry--) {
					gbcart_read(fd, i+0x4000, 4, rb);
					if (memcmp(rb, &rombank[i], 4)==0) break;
				}

				if (memcmp(rb, &rombank[i], 4)!=0) {
					printf("Verification error at 0x%X!\n", i);
					printf("File:  %02X %02X %02X %02X\n", rombank[i], rombank[i+1], rombank[i+2], rombank[i+3]);
					printf("Flash: %02X %02X %02X %02X\n", rb[0], rb[1], rb[2], rb[3]);
					exit(0);
				}
			}
#else
			int retry_time=200;
			for (int i=0; i<16*1024; i++) {
				gbcart_write_byte(fd, 0x2000, bank); //switch to bank
				if (gbcart_read_byte(fd, i+0x4000)==rombank[i]) continue;

				//Send quad write command
				//note: flash only uses first 12 address bits for commands: FFF
				poke_flashchip(fd, 0x0, 0xF0);  //<-- without this, *some* writes go bad.
				poke_flashchip(fd, 0xaaa, 0xaa);
				poke_flashchip(fd, 0x555, 0x55);
				poke_flashchip(fd, 0xaaa, 0xa0);
				gbcart_write_byte(fd, i+0x4000, rombank[i]);

				uint8_t res[2];
				if (i==0xaaa || i==0xaab) usleep(10000); //don't ask
				for (int retry=0; retry<retry_time; retry++) {
					res[0]=gbcart_read_byte(fd, i+0x4000);
					res[1]=gbcart_read_byte(fd, i+0x4000);
					if (res[0]==res[1] && res[1]==rombank[i]) break;
				}
				if (res[0]!=rombank[i]) {
					printf("Error writing bank %d addr 0x%X! Data %x read %x/%x\n", bank, i, rombank[i], res[0], res[1]);
					retry_time*=2;
					if (retry_time<6400) {
						i--;
					} else {
						printf("Ignoring error.\n");
					}
				} else {
					retry_time=200;
				}
			}
#endif
			bank++;
		}
		printf("Done, %d banks written.\n", bank);
	}

	close(fd);
	return 0;
}

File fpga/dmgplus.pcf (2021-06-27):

# Physical Constraints File for dmgplus.
# dmgplus has a ICe40HX4K-TQ144 chip.

set_io lcd_vsync 25
set_io lcd_altsig 26
set_io lcd_clk 28
set_io lcd_d[1] 29
set_io lcd_d[0] 31
set_io lcd_hsync 32
set_io lcd_datal 33
set_io lcd_control 34
set_io cart_a[2] 110
set_io cart_a[1] 112
set_io cart_a[0] 113
set_io rpi_g[1] 114
set_io rpi_g[2] 115
set_io rpi_b[1] 116
set_io rpi_b[0] 117
set_io rpi_dataen 118
set_io rpi_pclk 119
set_io cart_busdir 120
set_io cart_ncs 121
set_io cart_nrd 122
set_io rpi_g[0] 124
set_io cart_nwr 134
set_io cart_clk 135
set_io rpi_r[0] 136
set_io lp_clk 137
set_io lp_gp 138
set_io lp_din 139
set_io lp_dout 141
set_io cart_d[7] 73
set_io cart_d[6] 74
set_io cart_d[5] 75
set_io cart_d[4] 76
set_io cart_d[3] 78
set_io cart_d[2] 79
set_io cart_d[1] 80
set_io cart_d[0] 81
set_io cart_a[15] 82
set_io cart_a[14] 83
set_io rpi_vsync 84
set_io cart_a[13] 85
set_io cart_a[12] 87
set_io cart_a[11] 88
set_io cart_a[10] 90
set_io cart_a[9] 91
set_io cart_a[8] 93
set_io cart_a[7] 94
set_io cart_a[6] 95
set_io rpi_r[1] 104
set_io cart_a[5] 105
set_io cart_a[4] 106
set_io cart_a[3] 107
set_io cart_nrst 62
set_io spi_mosi 67
set_io spi_miso 68
set_io spi_sck 70
set_io spi_cs 71
set_io pwm_l 101
set_io pwm_r 102

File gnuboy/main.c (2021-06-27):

#undef _GNU_SOURCE
#define _GNU_SOURCE
#include <string.h>
#include <stdio.h>
#include <stdlib.h>

#include <stdarg.h>
#include <signal.h>

#include "input.h"
#include "rc.h"
#include "sys.h"
#include "rckeys.h"
#include "emu.h"
#include "exports.h"
#include "loader.h"

#include "Version"


static char *defaultconfig[] =
{
	"bind esc quit",
	"bind up +up",
	"bind down +down",
	"bind left +left",
	"bind right +right",
	"bind d +a",
	"bind s +b",
	"bind enter +start",
	"bind space +select",
	"bind tab +select",
	"bind joyup +up",
	"bind joydown +down",
	"bind joyleft +left",
	"bind joyright +right",
	"bind joy0 +b",
	"bind joy1 +a",
	"bind joy2 +select",
	"bind joy3 +start",
	"bind 1 \"set saveslot 1\"",
	"bind 2 \"set saveslot 2\"",
	"bind 3 \"set saveslot 3\"",
	"bind 4 \"set saveslot 4\"",
	"bind 5 \"set saveslot 5\"",
	"bind 6 \"set saveslot 6\"",
	"bind 7 \"set saveslot 7\"",
	"bind 8 \"set saveslot 8\"",
	"bind 9 \"set saveslot 9\"",
	"bind 0 \"set saveslot 0\"",
	"bind ins savestate",
	"bind del loadstate",
	"source gnuboy.rc",
	NULL
};


static void banner()
{
	printf("\ngnuboy " VERSION "\n");
}

static void copyright()
{
	banner();
	printf(
"Copyright (C) 2000-2001 Laguna and Gilgamesh\n"
"Portions contributed by other authors; see CREDITS for details.\n"
"\n"
"This program is free software; you can redistribute it and/or modify\n"
"it under the terms of the GNU General Public License as published by\n"
"the Free Software Foundation; either version 2 of the License, or\n"
"(at your option) any later version.\n"
"\n"
"This program is distributed in the hope that it will be useful,\n"
"but WITHOUT ANY WARRANTY; without even the implied warranty of\n"
"MERCHANTABILITY or FITNESS FOR A PARTICULAR PURPOSE.  See the\n"
"GNU General Public License for more details.\n"
"\n"
"You should have received a copy of the GNU General Public License\n"
"along with this program; if not, write to the Free Software\n"
"Foundation, Inc., 675 Mass Ave, Cambridge, MA 02139, USA.\n"
"\n");
}

static void usage(char *name)
{
	copyright();
	printf("Type %s --help for detailed help.\n\n", name);
	exit(1);
}

static void copying()
{
	copyright();
	exit(0);
}

static void help(char *name)
{
	banner();
	printf("Usage: %s [options] romfile\n", name);
	printf("\n"
"      --source FILE             read rc commands from FILE\n"
"      --bind KEY COMMAND        bind KEY to perform COMMAND\n"
"      --VAR=VALUE               set rc variable VAR to VALUE\n"
"      --VAR                     set VAR to 1 (turn on boolean options)\n"
"      --no-VAR                  set VAR to 0 (turn off boolean options)\n"
"      --showvars                list all available rc variables\n"
"      --help                    display this help and exit\n"
"      --version                 output version information and exit\n"
"      --copying                 show copying permissions\n"
"");
	exit(0);
}


static void version(char *name)
{
	printf("%s-" VERSION "\n", name);
	exit(0);
}


void doevents()
{
	event_t ev;
	int st;

	ev_poll();
	while (ev_getevent(&ev))
	{
		if (ev.type != EV_PRESS && ev.type != EV_RELEASE)
			continue;
		st = (ev.type != EV_RELEASE);
		rc_dokey(ev.code, st);
	}
}




static void shutdown()
{
	vid_close();
	pcm_close();
}

void die(char *fmt, ...)
{
	va_list ap;

	va_start(ap, fmt);
	vfprintf(stderr, fmt, ap);
	va_end(ap);
	exit(1);
}

static int bad_signals[] =
{
	/* These are all standard, so no need to #ifdef them... */
	SIGINT, SIGSEGV, SIGTERM, SIGFPE, SIGABRT, SIGILL,
#ifdef SIGQUIT
	SIGQUIT,
#endif
#ifdef SIGPIPE
	SIGPIPE,
#endif
	0
};

static void fatalsignal(int s)
{
	die("Signal %d\n", s);
}

static void catch_signals()
{
	int i;
	for (i = 0; bad_signals[i]; i++)
		signal(bad_signals[i], fatalsignal);
}



static char *base(char *s)
{
	char *p;
	p = strrchr(s, '/');
	if (p) return p+1;
	return s;
}


int main(int argc, char *argv[])
{
	int i;
	char *opt, *arg, *cmd, *s, *rom = 0;

	/* Avoid initializing video if we don't have to */
	for (i = 1; i < argc; i++)
	{
		if (!strcmp(argv[i], "--help"))
			help(base(argv[0]));
		else if (!strcmp(argv[i], "--version"))
			version(base(argv[0]));
		else if (!strcmp(argv[i], "--copying"))
			copying();
		else if (!strcmp(argv[i], "--bind")) i += 2;
		else if (!strcmp(argv[i], "--source")) i++;
		else if (!strcmp(argv[i], "--showvars"))
		{
			show_exports();
			exit(0);
		}
		else if (argv[i][0] == '-' && argv[i][1] == '-');
		else if (argv[i][0] == '-' && argv[i][1]);
		else rom = argv[i];
	}
	
	if (!rom) usage(base(argv[0]));

	/* If we have special perms, drop them ASAP! */
	vid_preinit();

	init_exports();

	s = strdup(argv[0]);
	sys_sanitize(s);
	sys_initpath(s);

	for (i = 0; defaultconfig[i]; i++)
		rc_command(defaultconfig[i]);

	cmd = malloc(strlen(rom) + 11);
	sprintf(cmd, "source %s", rom);
	s = strchr(cmd, '.');
	if (s) *s = 0;
	strcat(cmd, ".rc");
	rc_command(cmd);

	for (i = 1; i < argc; i++)
	{
		if (!strcmp(argv[i], "--bind"))
		{
			if (i + 2 >= argc) die("missing arguments to bind\n");
			cmd = malloc(strlen(argv[i+1]) + strlen(argv[i+2]) + 9);
			sprintf(cmd, "bind %s \"%s\"", argv[i+1], argv[i+2]);
			rc_command(cmd);
			free(cmd);
			i += 2;
		}
		else if (!strcmp(argv[i], "--source"))
		{
			if (i + 1 >= argc) die("missing argument to source\n");
			cmd = malloc(strlen(argv[i+1]) + 6);
			sprintf(cmd, "source %s", argv[++i]);
			rc_command(cmd);
			free(cmd);
		}
		else if (!strncmp(argv[i], "--no-", 5))
		{
			opt = strdup(argv[i]+5);
			while ((s = strchr(opt, '-'))) *s = '_';
			cmd = malloc(strlen(opt) + 7);
			sprintf(cmd, "set %s 0", opt);
			rc_command(cmd);
			free(cmd);
			free(opt);
		}
		else if (argv[i][0] == '-' && argv[i][1] == '-')
		{
			opt = strdup(argv[i]+2);
			if ((s = strchr(opt, '=')))
			{
				*s = 0;
				arg = s+1;
			}
			else arg = "1";
			while ((s = strchr(opt, '-'))) *s = '_';
			while ((s = strchr(arg, ','))) *s = ' ';
			
			cmd = malloc(strlen(opt) + strlen(arg) + 6);
			sprintf(cmd, "set %s %s", opt, arg);
			
			rc_command(cmd);
			free(cmd);
			free(opt);
		}
		/* short options not yet implemented */
		else if (argv[i][0] == '-' && argv[i][1]);
	}

	/* FIXME - make interface modules responsible for atexit() */
	atexit(shutdown);
	catch_signals();
	vid_init();
	pcm_init();

	rom = strdup(rom);
	sys_sanitize(rom);
	
	loader_init(rom);
	
	emu_reset();
	emu_run();

	/* never reached */
	return 0;
}

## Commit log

2018-08-05 Add code to sample video port of rpi
2018-08-29 Add pli-DING! startup sound generation logic; fix dithering logic to properly show grays
    [dmgplus.pcf, startupscreen_gen.v]
2018-08-30 Fix busy gen interpretation
    [startupscreen_gen.v]
2019-01-13 Add attempt at spi slave interface, plus testbed for it
2019-01-13 Spi slave seems to work under normal conditions.
2019-01-24 Create prelim spicart (spi<->cart iface) + testbench
2019-03-16 Error: fails at 0xAAB
    [main.c]
2019-03-17 Startup logo and SPI works.
2021-06-11 Modify FPGA flow: arachne -> nextpnr
2021-06-11 Do proper clock domain crossing of rpi rgb to vram, this removes artifacts on the screen. Also tweak ring osc stages; nextpnr made it too fast ^_^
2021-06-27 Add devicetree stuff
2021-06-27 Add KiCad PCB design files
    [Power.sch, cart_conn.sch, dmgplus.kicad_pcb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]
2021-06-27 Move spi-flash-reader stuff into its own subdir
